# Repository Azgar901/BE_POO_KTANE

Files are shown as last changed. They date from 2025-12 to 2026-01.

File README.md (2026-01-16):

# Rapport du BE C++ : Projet  KTANE 

Basé sur le jeu vidéo de coopération "Keep Talking And Nobody Explodes"

Le code de la Mega se trouve dans le dossier Projet_KTANE tandis que le code de l'ESP8266 se trouve dans le dossier ESP8266
## La bombe et sa composition

La bombe correspond à une classe ( Bomb ) comportant la durée du jeu et le nombre d'erreurs.
Pour éviter certains problèmes, nous avons ajouté un entier Update se mettant à jour pour chaque erreur.

Les modules de la bombe seront constitués d'un module de base servant à tous, puis par héritage chaque module sera défini.

### Module Timer et Gestion des erreurs

Ce module vise à définir la gestion du temps et des erreurs.

Il utilise les pins 38 et 53 pour les LEDs des erreurs et les pins 2 et  3 ( Digital PWM ) pour l'affichage ( Timer et Erreur ).
Les modules appellent la fonction AddError() pour ajouter une erreur sur la bombe. 
Le Timer se met à jour avec l'aide de la fonction millis() pour avoir de la précision.
Quand le Timer arrive à zéro la bombe fait un son d'explosion.

Les erreurs sont gérées dans la classe Bomb, où a chaque boucle on vérifie s'il y a eu une update, à ce moment, on allume une LED supplémentaire selon le nombre d'erreurs précédentes et on affiche Err 1 ou Err 2 pendant 1s.
Au bout de 3 erreurs la bombe se déclenche et affiche "LOSE" ( sauf pour les fils où la bombe marque "LOSE" si le fil coupé n'est pas bon ( explosion instantanée )).
Si la bombe a trois succès alors le timer affiche "YEAH" et une musique retentit.

### Module de base

Chaque module sera un héritage de cette classe, elle ne contient que l'état de la led de validation et l'adresse de la bombe.

### Premier Module
Voici le module "Thread":

Il s'agit de la première configuration (de 5 fils) dont le vrai fil à couper est le 4ième fil s'il y a deux fils jaunes et un seul fil rouge.
Pour cela, j'ai fait une classe "Thread" qui aura principalement une fonction permettant de configurer en mode Input les 5 pins (9, 10, 11, 12 et 13) que l'on utilisera pour les fils et une fonction qui permettra de détecter, en fonction de l'état des ports d'entrée de la carte (si une des broches n'est plus alimentée) permettra de savoir si un fil est déconnecté de la broche.
Si le fil coupé n'est pas situé sur la broche 13, la bombe se déclenche sinon la LED s'allume.

La LED de validation est situé sur la pin 26.

### Deuxième Module
Module "Simon":

Broches utilisées → - 41, 43, 45, 47 pour les boutons poussoir
                    - 40 (rouge), 42 (bleu), 44 (jaune), 46 (vert) pour les 4 LEDs du module
                    - 48 pour la LED de validation
Le but de ce module est d'apppuyer sur les boutons qui flashent dans un ordre qui est prédéfini dans notre programme (tableaux des erreurs). Nous avons choisi la configuration correspondant à un nnuméro de série qui contient au moins une voyelle dans le jeu originel.

Le module se comporte de 3 façons différentes en fonction du nombre d'erreurs fait. Au début de la partie, ce sera toujours la LED rouge qui flashera toutes les 4 secondes. À chaque erreur (2 maximum) il y a un ordre de couleurs différentes. Nous avons défini l'ordre des couleurs dans des matrices différentes: Tab_Error0, Tab_Error1 et Tab_Error2. Si un joueur se trompe, il reprendra à partir de la couleur à laquelle il a échoué mais la suite ne sera pas la même que dans les autres cas.
Au bout de 3 erreurs, la bombe se déclenche.

### Troisième Module

Module "Password" :

Utilisation des broches 6 pour la communication avec la télécommande et 7 pour la LED de validation.

Le module se sert de la communication entre la Mega 2560 et l'ESP8266 en USART.
La Mega récupère les touches de la télécommande à travers le module IR et 
convertit ensuite avec la fonction Navigate() en instructions pour l'ESP.
Cela se fait au travers de l'USART 1 ( broche 18 ) de la MEGA ( en Tx ) et en D5 ( Rx SoftWare) pour l'ESP. 
L'envoi de l'instruction se fait à travers une surcharge d'opérateur (>>) pour simplifier la lisibité du code de Telecommmand_Check().

Concernant le code de l'ESP, la Mega fournit les instructions à travers la fonction Navigate() et Put_Letter() et l'ESP récupère les instructions, compare le premier mot d'instruction et agit, pour la télécommande cela correspond à l'instruction "SET:".
Cela nous a permis d'ajouter un module Speaker dépendant de la classe Password en ajoutant l'instruction "PLAY:".

Les instructions de la télécommande sont décomposés en 3 parties : le nom de la commande, l'emplacement de la lettre à changer et la lettre à mettre.
Ainsi, sur l'écran LCD, on peut voir les lettres envoyées apparaitre, et celles-ci sont changés si l'on appuie sur la touche Up ou Down. 
On peut contrôler l'emplacement de la lettre avec les touches fast forward et fast backward. La validation du mot de passe s'effectue avec la touche EQ.

## Problèmes rencontrés

### Pour la Bombe

Sur le plan fonctionnel, nous avons voulu gérer les erreurs et le déclenchement de la bombe par exceptions. Cependant, nous nous sommes rendu compte qu'il nous était impossible de le faire car la carte que nous avons utilisé en plus pour notre projet (Arduino MEGA) ne contient pas le runtime d’exceptions AVR qui permet de linker avec try et catch. On a du donc abandonné l'idée.

### Pour le timer

Compliqué à mettre en place, nous avions d'abord prévu de le faire par interruption, mais cela rendait le code très compliqué et il aurait fallu faire les autres fonctions par interruption. 
On a donc changé pour la fonction millis() plus simple d'utilisation. Cela permet au Timer de ne jamais se bloquer. 

L'affichage n'était pas simple, nous voulions à la base utilisée la surcharge d'opérateur pour décompter le timer mais cela ne menait qu'à davantage de difficulté inutile.
Alors, nous avons juste utilisé un int permettant de décompter.

### Pour les Fils

Difficulté de réalisation, les fils utilisent la fonction output pullup des gpios mais nous voulions faire l'inverse ( si l'état est bas alors le fil est coupé )
mais cela créait des broches flottantes qui n'étaient pas détectées.

### Pour le Simon

Difficulté de compréhension, nous avons dû revoir tout notre code sur un tableau ( toute une après-midi ) pour être sûr de ce qu'on faisait et que nous soyons clairs sur la démarche du module.
La gestion de clignotement des leds étaient aussi compliqués dans la logique de gestion ( selon si on appuie sur un bouton ou non ) faisant appel de nombreuses fois à la fonction millis.

### Pour le Password

Difficulté de syntaxe, première utilisation du module IRreceiver ayant une syntaxe particulière puis affichage sur le LCD avec la carte ESP8266.
Nous avons aussi voulu utilisé la STL dans le code pour avoir l'algorithme d'égalité de deux tableaux sauf que la MEGA ne supporte pas ArduinoSTL, nous avons donc décidé de ne pas l'utiliser.

### Pour la sortie audio

Nous voulions absolument une sortie audio pour la bombe, premier essai sans amplificateur audio ( seulement un transistor NPN ) et en wifi. Le résultat est un son très faible avec plus de grésillements que de signal voulu. 
Avec l'utilisation de l'amplificateur audio le son n'était que plus fort et nous avons du oublié l'utilisation du wifi pour l'audio.

Après ces échecs, nous avons essayé de mettre la partie audio sur la Mega mais celle-ci n'a pas assez de mémoire flash donc deuxième abandon.

Nous avons donc repris l'ESP8266 et avons découvert la librairie LittleFS pas trop complexe d'utilisation et qui permet d'envoyer un fichier directement dans la mémoire de l'ESP.

# Partie Conception

La bombe a été créé à partir de casier de rangement imprimé en 3D par nos soins avec l'utilisation du modèle STL " Interlocking Drawer " trouvé sur Thingiverse : https://www.thingiverse.com/thing:2539830.
Nous avons apporté des modifications au fichier de base ( notamment l'ouverture interne de la carte ).

La conception de l'intérieur a été faite sur-mesure en fonction des composants de chaque module, toujours imprimé en 3D permettant de faire des essais/erreurs.
La conception nous a permis de nous faire continuer d'apprendre la modélisation 3D.

Tous les fichiers STL et 3mf ( dont les erreurs )sont dans le dossier 3D File.

Les boutons ont ensuite été soudé avec les câbles et nous avons torsadé les câbles autour des lEDS ( LED + résistance ).

## Difficultés rencontrées

La gestion interne de la bombe a été compliqué, il a fallu concevoir une architecture solide mais permettant une modularité si l'on veut changer les modules( d'où l'utilisation de casier encastré ) même si cette idée a été un peu abandonnée par manque de temps.

Il a fallu ensuite prendre les mesures de chaque composant et faire des tests lors de la création interne modules pour être sûr que le composant pouvait rester en place.

L'écran LCD a posé des problèmes car il est plus grand que le casier, nous avons donc dû modifier davantage le fichier STL pour créer une encoche sur le dessus et adapter l'intérieur du casier pour pouvoir ajouter la LED et le module IR.

Le plus gros problème a été l'assemblage final et cela venait de l'utilisation des casiers modulables car pour assembler les casiers il faut les encaster par le haut ou le bas.
Ce que nous n'avions pas pris en compte a été le nombre total de fils. Il fallait que tous les fils restent connectés mais nous avons majoritairement utilisés des fils Dupont mâle-mâle ou mâle-femelle ce qui n'aidaient pas au maintien.
Nous avons donc commencé par le Simon ( le plus cablé et moins accessible ), facile à faire mais il a ensuite fallu connecter le timer et placer la Mega à l'intérieur. 
Ici vient deux problèmes : les câbles du Simon se détachent et la carte passe à peine dans son encadrement prévu ( entre les 4 modules ). Nous avons donc dû à de nombreuses reprises rebrancher les fils à la pincette puis percé un trou pour la Mega.
Nous avons ensuite eu des difficultés à placer les deux derniers casiers car il fallait lever la carte pour faire passer les casiers par le haut et le tout sans débrancher les câbles déjà placés, parce qu'ils ne seront plus accessibles.

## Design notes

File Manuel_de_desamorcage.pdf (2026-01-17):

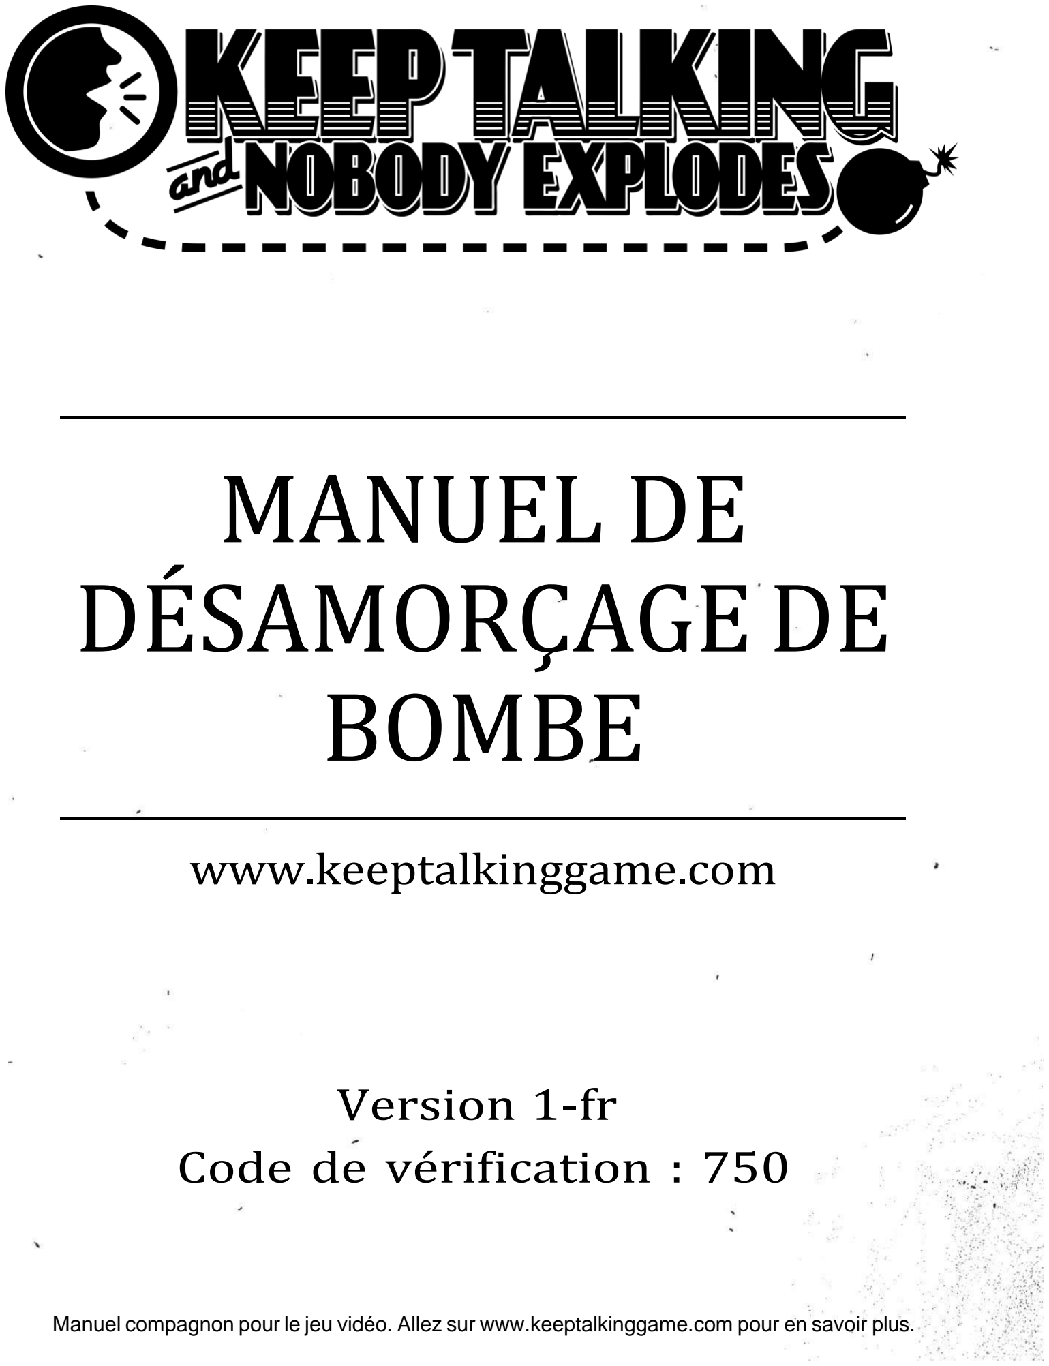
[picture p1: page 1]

# MANUEL DE DÉSAMORÇAGE DE BOMBE

# www.keeptalkinggame.com

# Version 1-fr Code de vérification : 750

Manuel compagnon pour le jeu vidéo. Allez sur www.keeptalkinggame.com pour en savoir plus.

Keep Talking and Nobody Explodes v. 1-fr | Introduction

Bienvenue dansle monde dangereux et difficile des désamorceurs de bombes.

ÉtudieZ ce manuel attentivement ; vous êtesl'expert. Dans ces pages, voustrouvereZ toutes les informations nécessaires pour désamorcer même les bombes les plus coriaces.
Et n'oublieZ pas — un seul oubli et tout pourrait se terminer ! Bonne chance !
Matérialisée par LELENGOLI Bernys et MELADE Ulrich. Nos remerciements à BENOIT Arwen.

Page l

# Désarmorcer des bombes

Une bombe explose lorsque son compte à rebours atteint 0:00 ou lorsque trop d'erreurs ont été commises. Le seul moyen de désamorcer une bombe avant qu'elle n'explose est de désarmer chaque module séparément avant que le compte à rebours ne se termine.

Exemple d'une bombe

Face | Côté

Modules

Chaque bombe aura jusqu'à 11 modules qui devront être désarmés. Chaque module est indépendant. Ils peuvent être désamorcés dans n'importe quel ordre.

Les instructions pour désarmer les modules peuvent être trouvées dans la Section
1. Les modules "Demandants" sont une exception et sont décrits dans la Section l.

Erreurs

Si le désamorceur fait une erreur, la bombe enregistre une erreur qui
est montrée au-dessus du compte à rebours. Les bombes avec un compteur d'erreur exploseront à la troisième erreur. Le compte à rebours ira plus vite à chaque erreur commise.

Indicateur
d'erreur

S'il n'y a pas d'indicateur au-dessus du compte à rebours, la bombe explosera à la première faute commise, ne laissant aucune place à l'erreur.

Obtenir des informations

Certaines instructions pour désarmer des modules nécessiteront des informations spécifiques sur la bombe, comme le numéro de série. Ce type d'information se trouve typiquement sur les côtés de la bombe. Se référer aux annexes A, B et C pour plus d'informations d'identification qui seront utiles pour désarmer certains modules.

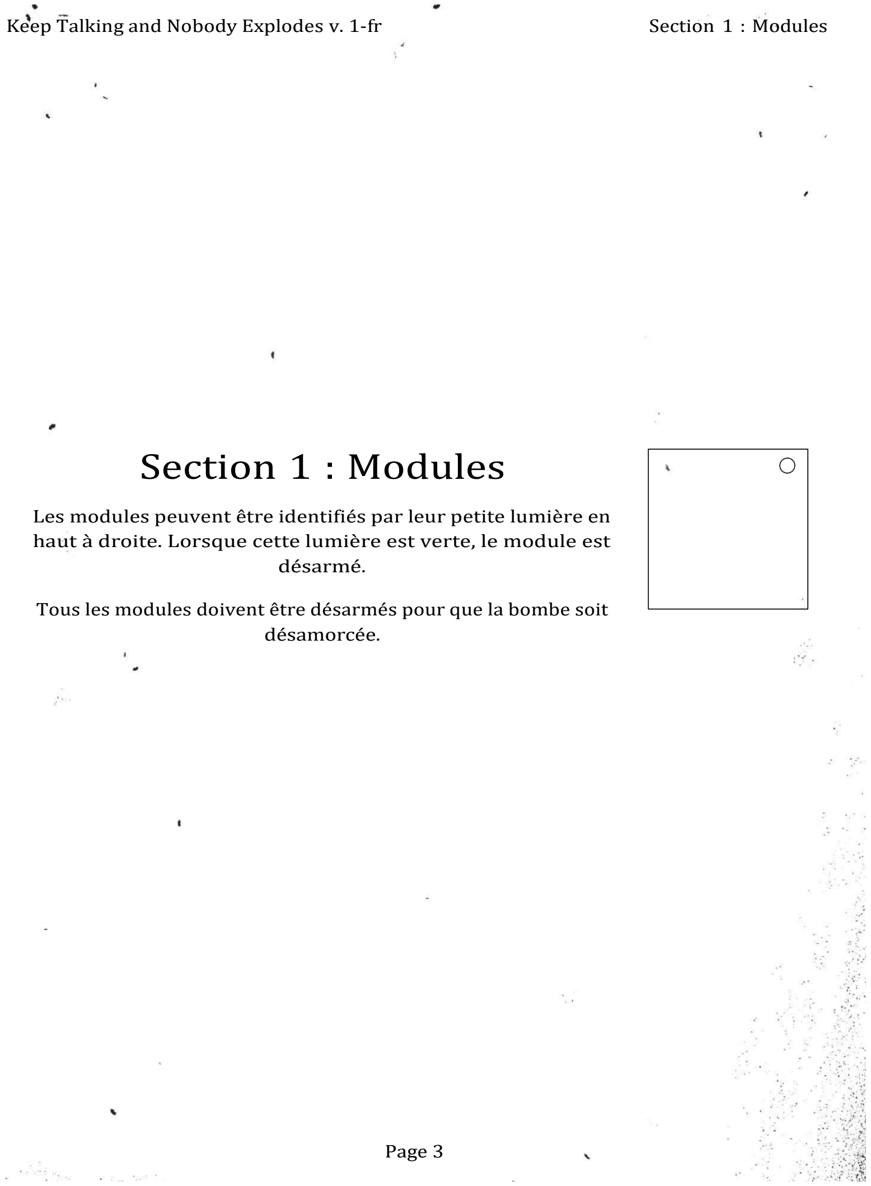
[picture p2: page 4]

Keep Talking and Nobody Explodes v. 1-fr | Section 1 : Modules

# Section 1 : Modules

Les modules peuvent être identifiés par leur petite lumière en haut à droite. Lorsque cette lumière est verte, le module est désarmé.

Tous les modules doivent être désarmés pour que la bombe soit désamorcée.

Keep Talking and Nobody Explodes v. 1-fr | Fils

## À propos des Fils

Lesfilssont comme le sang de l'électronique ! Non... L'électricité est le sang. Lesfils sont plus comme les artères. Les veines ? Peu importe...

Un module de fils peut contenir entre 3 et 6 fils.
Seul un fil a besoin d'être coupé pour désarmer le module. Les fils sont ordonnés de haut en bas.

3 fils :
S'il n'y a pas de fil rouge, couper le troisième fil.
Sinon, si le dernier fil est blanc, couper le premier fil. Sinon, s'il y a plus d'un fil bleu, couper le dernier fil rouge.
Sinon, couper le quatrième fil.

4 fils :
S'il y a plus d'un fil rouge et si le dernier chiffre du numéro de série est
impair, couper le dernier fil jaune.
Sinon, si le dernier filestjaune et s'il n'y a pas de fil blanc, couper le dernier fil. Sinon, s'il y a exactement un fil bleu, couper le.
Sinon, s'il y a plus d'un fil jaune, couper le premier fil.
Sinon, couper le troisième fil.

5 fils :
Si le dernier filest vertet si le dernier chiffre du numéro de série est impair, couper le dernier fil.
Sinon, s'il y a exactement un fil blanc et plus d'un fil jaune, couper le premier fil.
Sinon, s'il n'y a pas de fil noir, couper le premier fil.
Sinon, couper le cinquième fil.

6 fils :
S'il n'y a pas de fil bleu et si le dernier chiffre du numéro de série est impair, couper le deuxième fil.
Sinon, s'il y a exactement un fil noir et plus d'un fil blanc, couper le troisième fil. Sinon, s'il n'y a pas de fil rouge, couper le premier fil.
Sinon, couper le cinquième fil.

Keep Talking and Nobody Explodes v. 1-fr | Bouton

## À propos du Bouton

On pourrait penser qu'appuyer sur un bouton est asseZ simple. C'est en pensant de cette façon que des bombes explosent.

Se référer à l'annexe A pour identifier les indicateurs.
Se référer à l'annexe B pour identifier les piles.

Suivre ces règles dans l'ordre dans lequel elles sont listées.
Effectuer la première action qui répond aux critères :
1. Si le bouton est bleu et est marqué « Annuler », maintenir le bouton appuyé et se référer à « Relâcher un bouton enfoncé ».
l. S'il y a plus d'une pile sur la bombe et si le bouton est marqué « Exploser », appuyer et immédiatement relâcher le bouton.
3. Si le bouton est blanc et s'il y a un indicateur allumé avec les lettres CAR, maintenir le bouton appuyé et se référer à « Relâcher un bouton enfoncé ».
4. S'il y a plus de deux piles sur la bombe et s'il y a un indicateur allumé avec les lettres FRK, appuyer et immédiatement relâcher le bouton.
5. Si le bouton est jaune, maintenir le bouton appuyé et se référer à « Relâcher un bouton enfoncé ».
6. Si le bouton est rouge et est marqué « Maintenir », appuyer et immédiatement relâcher le bouton.
7. Si aucune des règles ne correspond, maintenir le bouton appuyé et se référer à « Relâcher un bouton enfoncé ».

Relâcher un bouton enfoncé

Lors de l'appui sur le bouton, une bande colorée s'allume sur le côté droit du module. Relâcher alors le bouton à un moment spécifique en fonction de la couleur de cette bande :

Bande bleue : relâcher lorsque le compte à rebours affiche un 4 à n'importe quelle position.
Bande blanche : relâcher lorsque le compte à rebours affiche un 1 à n'importe quelle position.
Bande jaune : relâcher lorsque le compte à rebours affiche un 5 à n'importe quelle position.
Bande d'une autre couleur : relâcher lorsque le compte à rebours affiche un 1 à n'importe quelle position.

## À propos du Clavier

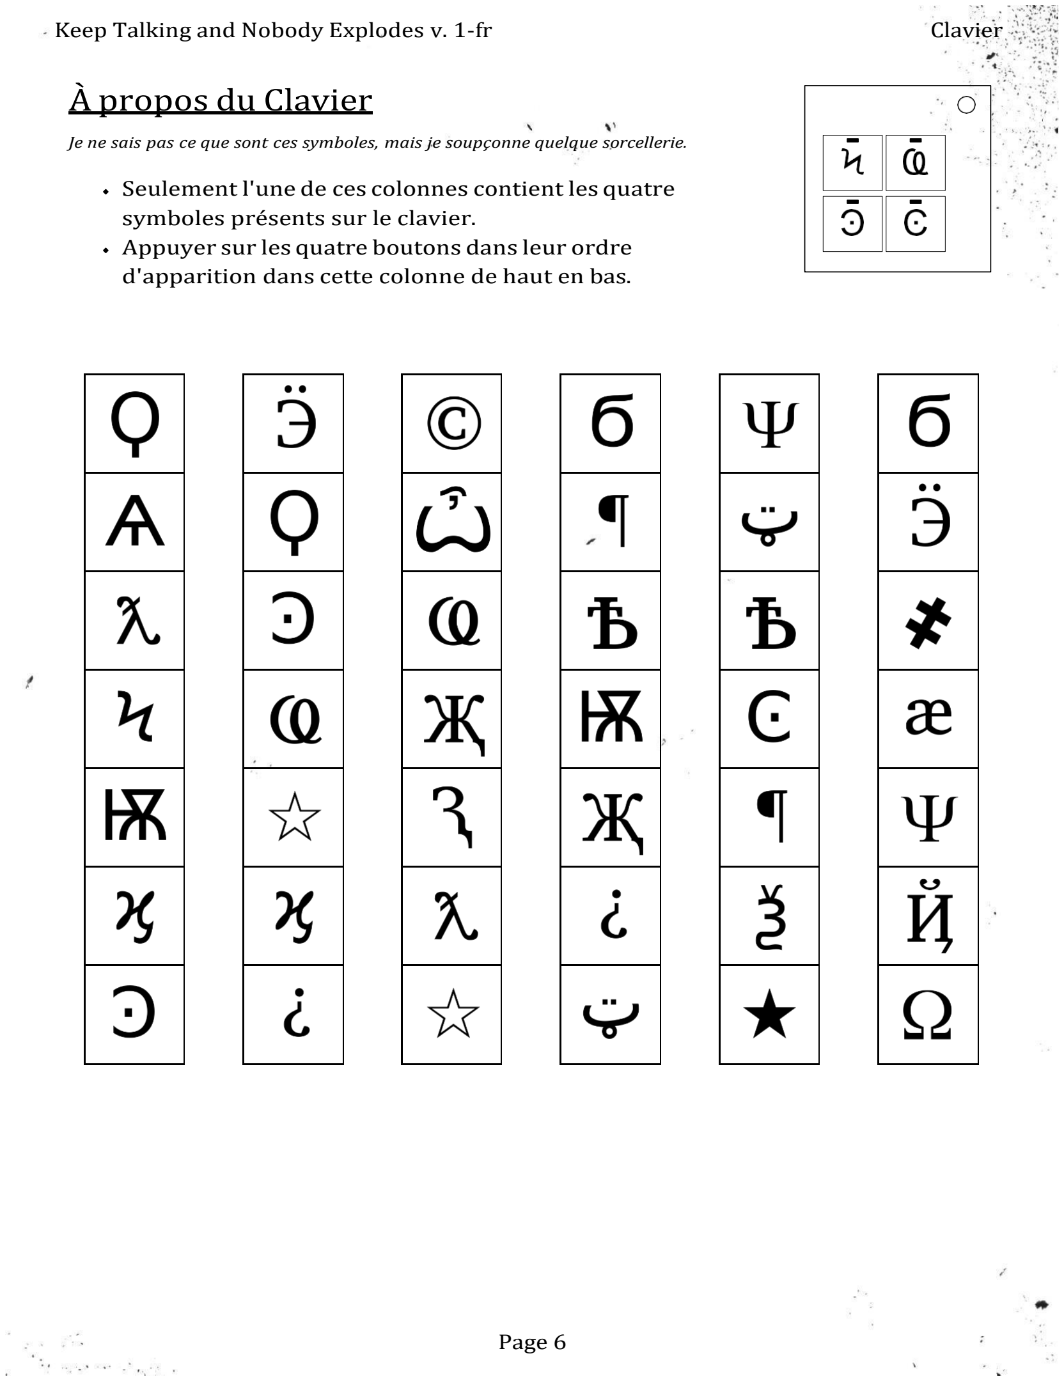
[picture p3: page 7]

Keep Talking and Nobody Explodes v. 1-fr | Clavier

Je ne sais pas ce que sont ces symboles, mais je soupçonne quelque sorcellerie.

Seulement l'une de ces colonnes contient les quatre symboles présents sur le clavier.
Appuyer sur les quatre boutons dans leur ordre d'apparition dans cette colonne de haut en bas.

Keep Talking and Nobody Explodes v. 1-fr | Simon

## À propos du Simon

Les modules peuvent être identifiés par leur petite lumière en haut à droite. Lorsque cette lumière est verte, le module est désarmé.

1. Un des quatre boutons s'allumera.
l. En utilisant la table ci-dessous, appuyer sur le bouton correspondant.
3. Le bouton original s'allumera suivi d'un autre. Répéter la
séquence dans l'ordre en utilisantla correspondance des couleurs.
4. La séquence s'allongera d'une couleur à chaque fois que la bonne séquence sera entrée, jusqu'à ce que le module soit désarmé.

## Rouge Vert

## Bleu Jaune

Si le numéro de série contient au moins une voyelle :

Flash Rouge | Flash Bleu | Flash Vert | Flash Jaune
Bouton à appuyer : | Pas d'erreur | Bleu | Rouge | Jaune | Vert
| 1 erreur | Jaune | Vert | Bleu | Rouge
| l erreurs | Vert | Rouge | Jaune | Bleu

Si le numéro de série ne contient pas de voyelle :

Flash Rouge | Flash Bleu | Flash Vert | Flash Jaune
Bouton à appuyer : | Pas d'erreur | Bleu | Jaune | Vert | Rouge
| 1 erreur | Rouge | Bleu | Jaune | Vert
| l erreurs | Jaune | Vert | Bleu | Rouge

## À propos du Labyrinthe

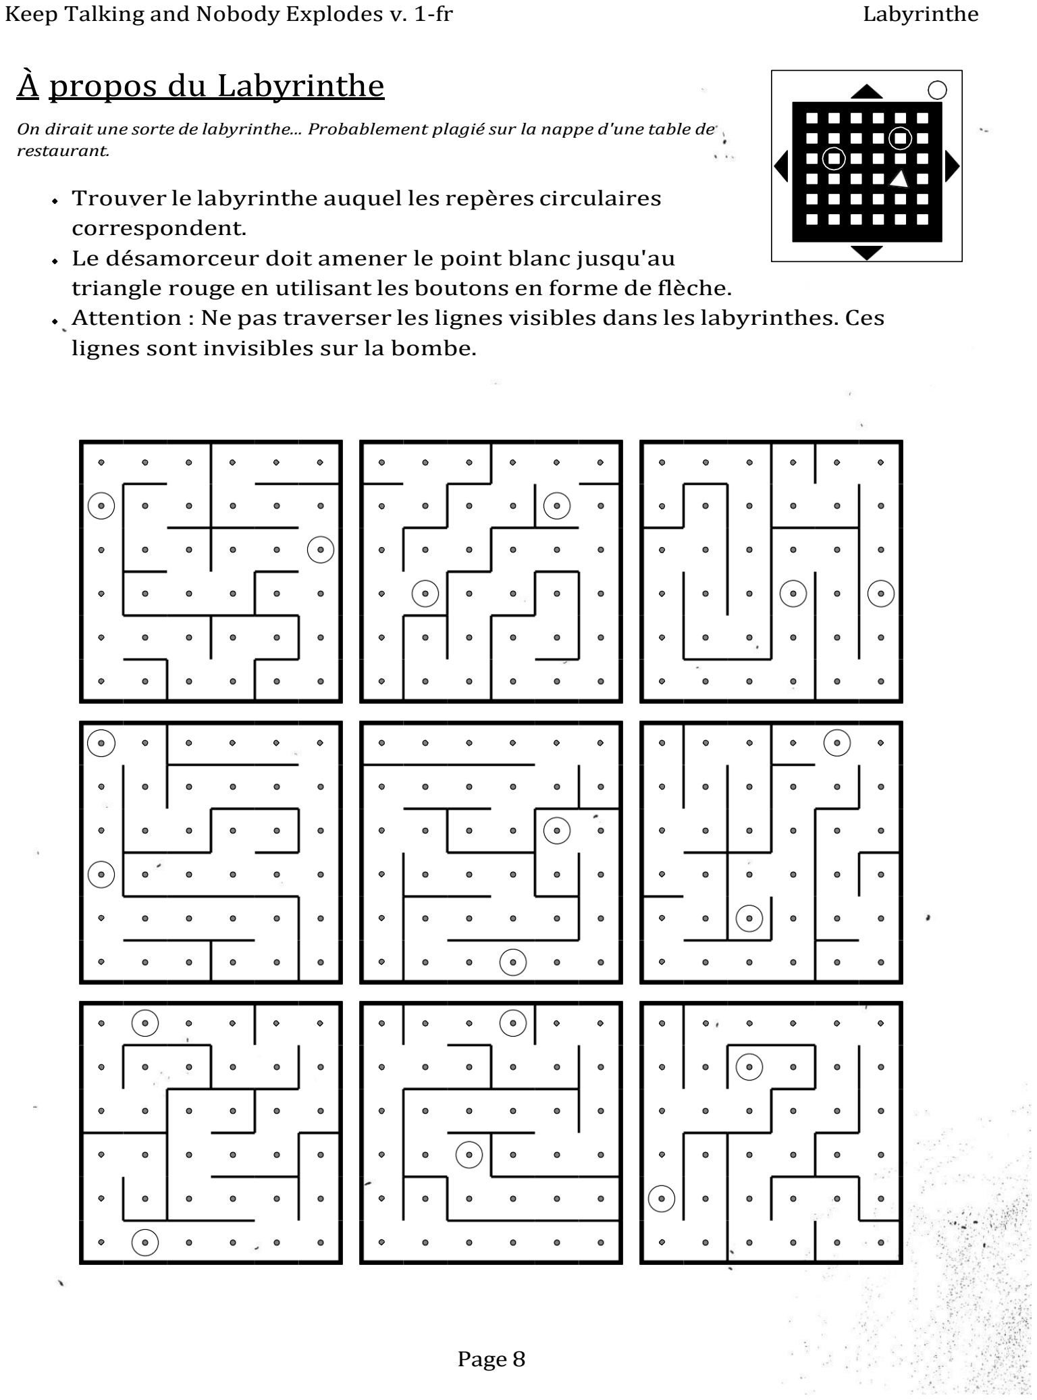
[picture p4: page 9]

Keep Talking and Nobody Explodes v. 1-fr | Labyrinthe

On dirait une sorte de labyrinthe... Probablement plagié sur la nappe d'une table de restaurant.

Trouver le labyrinthe auquel les repères circulaires correspondent.
Le désamorceur doit amener le point blanc jusqu'au
triangle rouge en utilisant les boutons en forme de flèche.
Attention : Ne pas traverser les lignes visibles dans les labyrinthes. Ces lignes sont invisibles sur la bombe.

## À propos de Jeux de mots

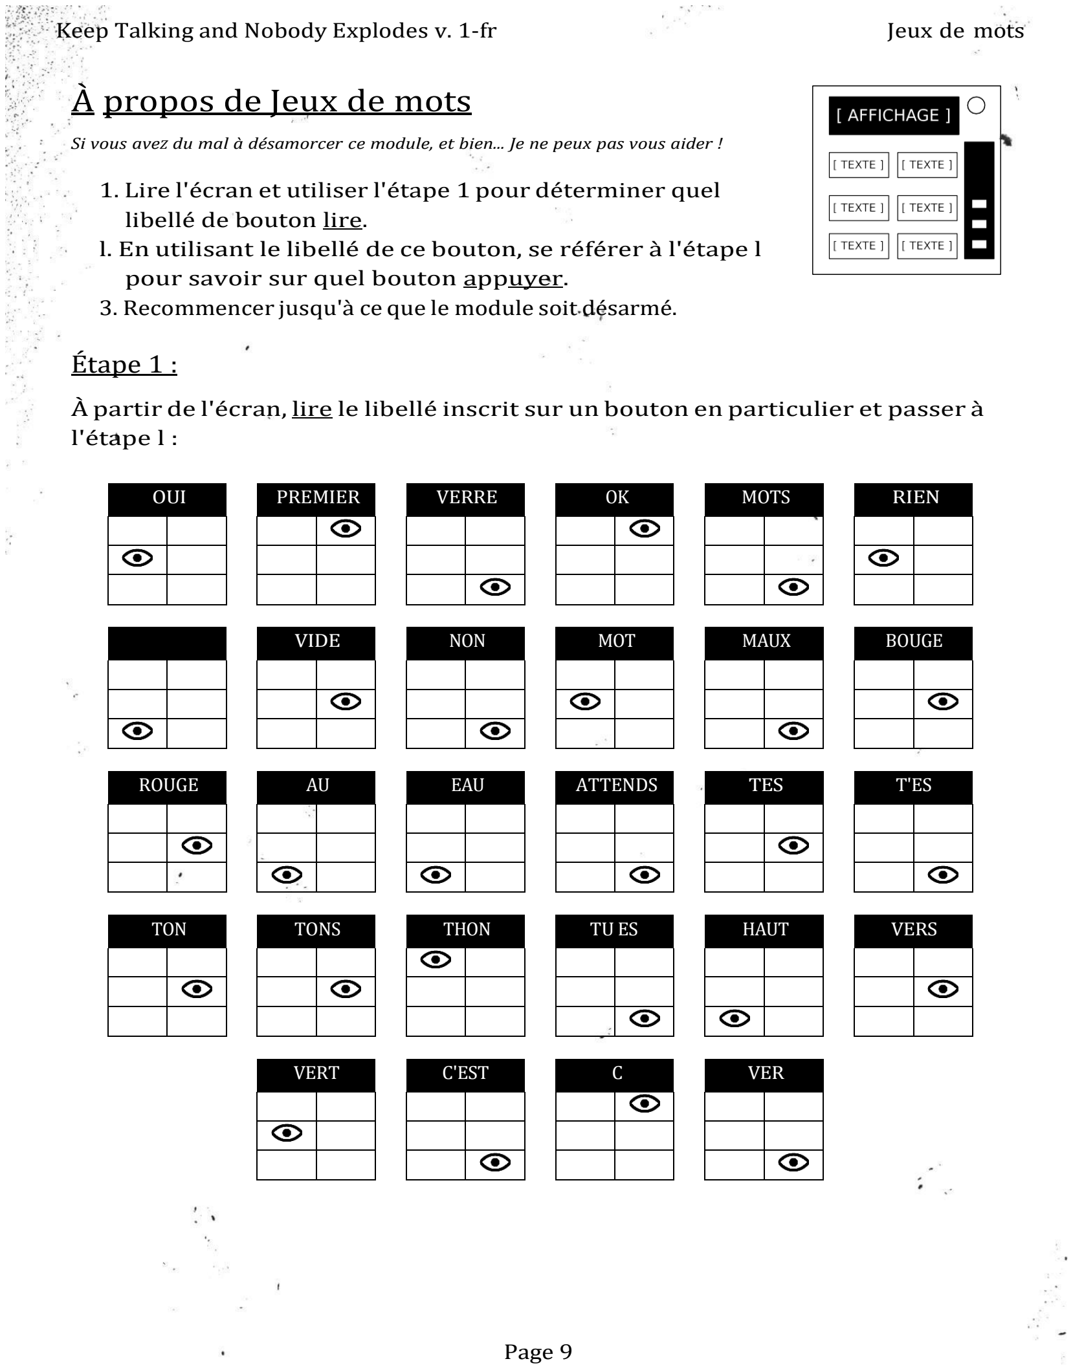
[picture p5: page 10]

Keep Talking and Nobody Explodes v. 1-fr | Jeux de mots

Si vous aveZ du mal à désamorcer ce module, et bien... Je ne peux pas vous aider !

1. Lire l'écran et utiliser l'étape 1 pour déterminer quel libellé de bouton lire.
l. En utilisant le libellé de ce bouton, se référer à l'étape l pour savoir sur quel bouton appuyer.
3. Recommencer jusqu'à ce que le module soit désarmé.

Étape 1 :

À partir de l'écran, lire le libellé inscrit sur un bouton en particulieret passerà l'étape l :

OUI | PREMIER | VERRE | OK | MOTS | RIEN
VIDE | NON | MOT | MAUX | BOUGE
ROUGE | AU | EAU | ATTENDS | TES | T'ES
TON | TONS | THON | TU ES | HAUT | VERS
VERT | C'EST | C | VER

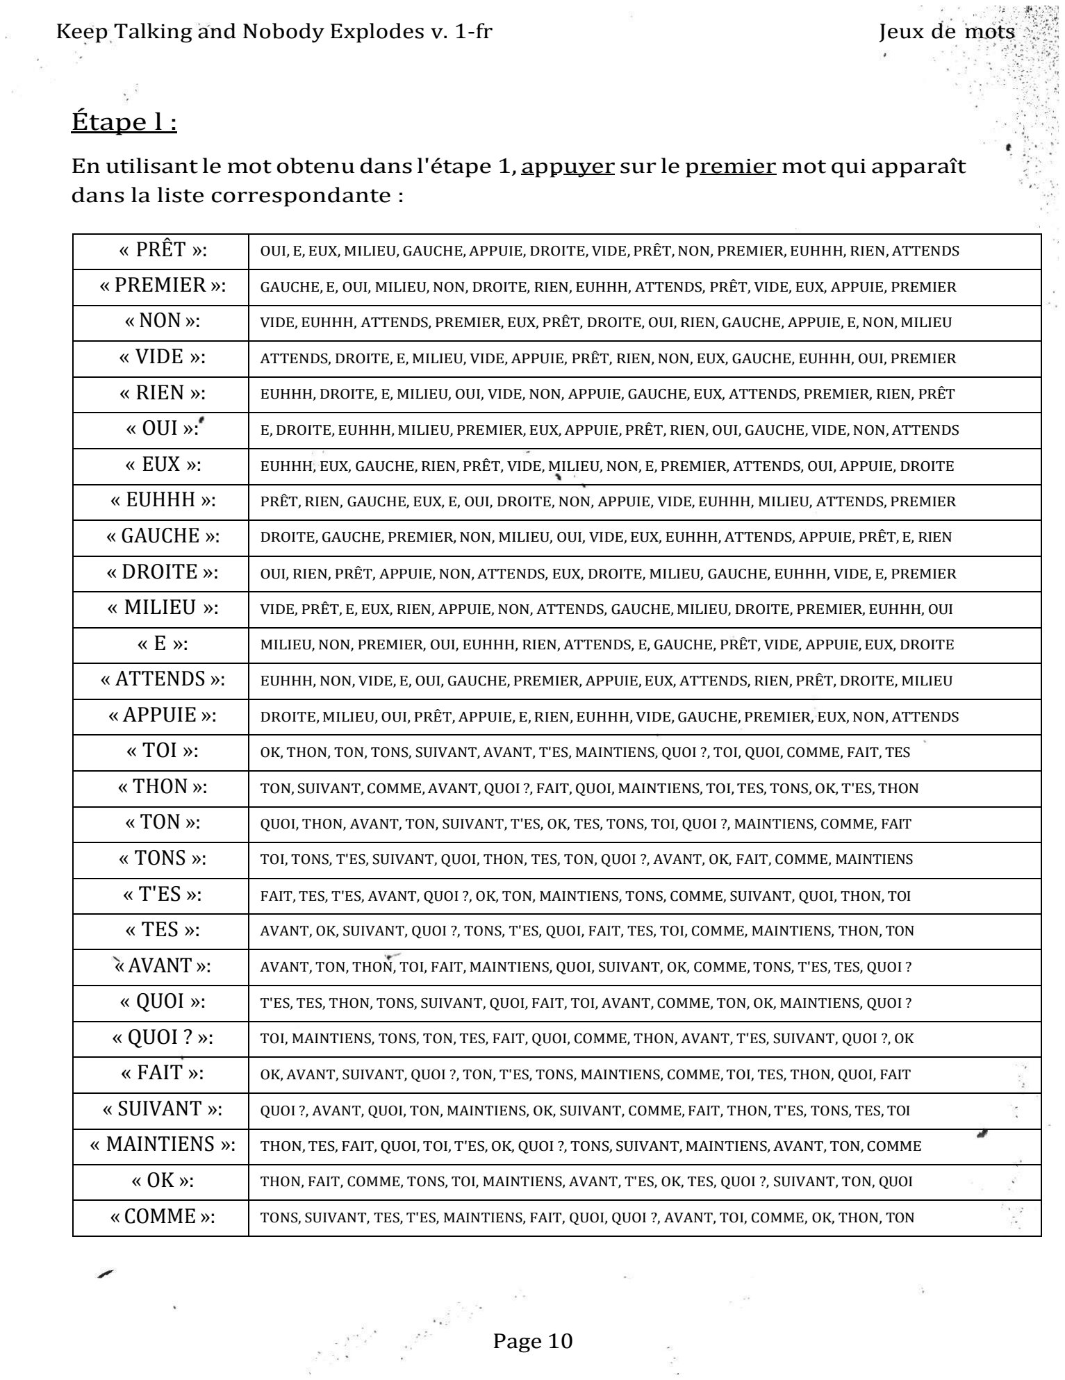
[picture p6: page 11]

Keep Talking and Nobody Explodes v. 1-fr | Jeux de mots

Étape l :

En utilisantle mot obtenu dans l'étape 1, appuyer sur le premier mot qui apparaît dans la liste correspondante :

« PRÊT »: | OUI, E, EUX, MILIEU, GAUCHE, APPUIE, DROITE, VIDE, PRÊT,NON, PREMIER, EUHHH, RIEN, ATTENDS
« PREMIER »: | GAUCHE, E, OUI, MILIEU, NON, DROITE, RIEN, EUHHH, ATTENDS, PRÊT, VIDE, EUX, APPUIE, PREMIER
« NON»: | VIDE, EUHHH, ATTENDS, PREMIER, EUX, PRÊT, DROITE, OUI, RIEN, GAUCHE, APPUIE, E,NON, MILIEU
« VIDE »: | ATTENDS, DROITE, E, MILIEU, VIDE, APPUIE, PRÊT, RIEN, NON, EUX, GAUCHE, EUHHH, OUI, PREMIER
« RIEN »: | EUHHH, DROITE, E, MILIEU, OUI, VIDE, NON, APPUIE, GAUCHE, EUX, ATTENDS, PREMIER, RIEN, PRÊT
« OUI »: | E,DROITE, EUHHH, MILIEU, PREMIER, EUX, APPUIE, PRÊT, RIEN, OUI, GAUCHE, VIDE,NON, ATTENDS
« EUX »: | EUHHH, EUX, GAUCHE, RIEN, PRÊT, VIDE, MILIEU, NON, E, PREMIER, ATTENDS, OUI, APPUIE, DROITE
« EUHHH »: | PRÊT, RIEN, GAUCHE, EUX, E, OUI, DROITE, NON, APPUIE, VIDE, EUHHH, MILIEU, ATTENDS, PREMIER
« GAUCHE »: | DROITE, GAUCHE, PREMIER, NON, MILIEU, OUI, VIDE, EUX, EUHHH, ATTENDS, APPUIE, PRÊT, E, RIEN
« DROITE »: | OUI, RIEN, PRÊT, APPUIE, NON, ATTENDS, EUX, DROITE, MILIEU, GAUCHE, EUHHH, VIDE, E, PREMIER
« MILIEU »: | VIDE, PRÊT, E, EUX, RIEN, APPUIE, NON, ATTENDS, GAUCHE, MILIEU, DROITE, PREMIER, EUHHH, OUI
« E »: | MILIEU, NON, PREMIER, OUI, EUHHH, RIEN, ATTENDS, E, GAUCHE, PRÊT, VIDE, APPUIE, EUX, DROITE
« ATTENDS »: | EUHHH, NON, VIDE, E, OUI, GAUCHE, PREMIER, APPUIE, EUX, ATTENDS, RIEN, PRÊT, DROITE, MILIEU
« APPUIE »: | DROITE, MILIEU, OUI, PRÊT, APPUIE, E, RIEN, EUHHH, VIDE, GAUCHE, PREMIER, EUX,NON, ATTENDS
« TOI »: | OK, THON, TON, TONS, SUIVANT, AVANT, T'ES, MAINTIENS, QUOI ?, TOI, QUOI, COMME, FAIT, TES
« THON »: | TON, SUIVANT, COMME, AVANT, QUOI ?, FAIT,QUOI, MAINTIENS, TOI, TES, TONS, OK, T'ES, THON
« TON »: | QUOI, THON, AVANT, TON, SUIVANT, T'ES, OK, TES, TONS, TOI, QUOI ?, MAINTIENS, COMME, FAIT
« TONS »: | TOI, TONS, T'ES, SUIVANT, QUOI, THON, TES, TON, QUOI ?, AVANT, OK, FAIT, COMME, MAINTIENS
« T'ES »: | FAIT, TES, T'ES, AVANT, QUOI ?, OK, TON, MAINTIENS, TONS, COMME, SUIVANT, QUOI, THON, TOI
« TES »: | AVANT, OK, SUIVANT, QUOI ?, TONS, T'ES, QUOI, FAIT, TES, TOI, COMME, MAINTIENS, THON, TON
«AVANT »: | AVANT, TON, THON, TOI, FAIT, MAINTIENS, QUOI, SUIVANT, OK, COMME, TONS, T'ES, TES, QUOI ?
« QUOI »: | T'ES, TES, THON, TONS, SUIVANT, QUOI, FAIT, TOI, AVANT, COMME, TON, OK, MAINTIENS, QUOI ?
« QUOI ? »: | TOI, MAINTIENS, TONS, TON, TES, FAIT, QUOI, COMME, THON, AVANT, T'ES, SUIVANT, QUOI ?, OK
« FAIT »: | OK, AVANT, SUIVANT, QUOI ?, TON, T'ES, TONS, MAINTIENS, COMME, TOI, TES, THON, QUOI, FAIT
« SUIVANT »: | QUOI ?, AVANT, QUOI, TON, MAINTIENS, OK, SUIVANT, COMME, FAIT, THON, T'ES, TONS, TES, TOI
« MAINTIENS »: | THON,TES, FAIT, QUOI, TOI, T'ES, OK, QUOI ?, TONS, SUIVANT, MAINTIENS, AVANT, TON, COMME
« OK »: | THON, FAIT, COMME, TONS, TOI, MAINTIENS, AVANT, T'ES, OK, TES, QUOI ?, SUIVANT, TON, QUOI
« COMME »: | TONS, SUIVANT, TES, T'ES, MAINTIENS, FAIT, QUOI, QUOI ?, AVANT, TOI, COMME, OK, THON, TON

Keep Talking and Nobody Explodes v. 1-fr | Simon

## À propos du Simon

Les modules peuvent être identifiés par leur petite lumière en haut à droite. Lorsque cette lumière est verte, le module est désarmé.

1. Un des quatre boutons s'allumera.
l. En utilisant la table ci-dessous, appuyer sur le bouton correspondant.
3. Le bouton original s'allumera suivi d'un autre. Répéter la
séquence dans l'ordre en utilisant la correspondance des couleurs.
4. La séquence s'allongera d'une couleur à chaque fois que la bonne séquence sera entrée, jusqu'à ce que le module soit désarmé.

## Rouge Vert

## Bleu Jaune

Si le numéro de série contient au moins une voyelle :

Flash Rouge | Flash Bleu | Flash Vert | Flash Jaune
Bouton à appuyer : | Pas d'erreur | Jaune | Vert | Bleu | Rouge
| 1 erreur | Bleu | Jaune | Vert | Rouge
| 2 erreurs | Rouge | Bleu | Jaune | Vert

Si le numéro de série ne contient pas de voyelle :

Flash Rouge | Flash Bleu | Flash Vert | Flash Jaune
Bouton à appuyer : | Pas d'erreur | Jaune | Rouge | Bleu | Vert
| 1 erreur | Bleu | Jaune | Rouge | Vert
| 2 erreurs | Vert | Bleu | Jaune | Rouge

Keep Talking and Nobody Explodes v. 1-fr | Memory

## À propos du Memory

La mémoire est une chose fragile, mais bon tout l’est quand une bombe explose, alors faites attention !

Appuyer sur la bonne touche pour aller à la prochaine étape. Compléter toutes les étapes pour désarmer le module. Appuyer sur un bouton incorrect vous fera revenir à l'étape 1.
Les boutons sont ordonnés de gauche à droite.

Étape 1 :

Si l'écran affiche 1, appuyer sur le bouton en deuxième position. Si l'écran affiche l, appuyer sur le bouton en deuxième position. Si l'écran affiche 3, appuyer sur le bouton en troisième position. Si l'écranaffiche 4, appuyer sur le bouton en quatrième position.

Étape l :

Si l'écran affiche 1, appuyer sur le bouton portant le chiffre « 4 » .
Si l'écran affiche l, appuyer sur le bouton à la même positionqu'à l'étape 1. Si l'écran affiche 3, appuyer sur le bouton en première position.
Si l'écran affiche 4, appuyer sur le bouton à la même position qu'à l'étape 1.

Étape 3 :

Si l'écran affiche 1, appuyer sur le bouton ayant le même chiffre qu'à l'étape l. Si l'écran affiche l, appuyer sur le bouton ayant le même chiffre qu'à l'étape 1. Si l'écran affiche 3, appuyer sur le bouton en troisième position.
Si l'écran affiche 4, appuyer sur le bouton portant le chiffre « 4 » .

Étape 4 :

Si l'écran affiche 1, appuyer sur le bouton à la même position qu'à l'étape 1. Si l'écran affiche l, appuyer sur le bouton en première position.
Si l'écran affiche 3, appuyer sur le bouton à la même positionqu'à l'étape l. Si l'écran affiche 4, appuyer sur le bouton à la même position qu'à l'étape l.

Étape 5 :

Si l'écran affiche 1, appuyer sur le bouton ayant le même chiffre qu'à l'étape 1. Si l'écran affiche l, appuyer sur le bouton ayant le même chiffre qu'à l'étape l. Si l'écran affiche 3, appuyer sur le bouton ayant le même chiffre qu'à l'étape 4. Si l'écran affiche 4, appuyer sur le bouton ayant le même chiffre qu'à l'étape 3.

## À propos du Code Morse

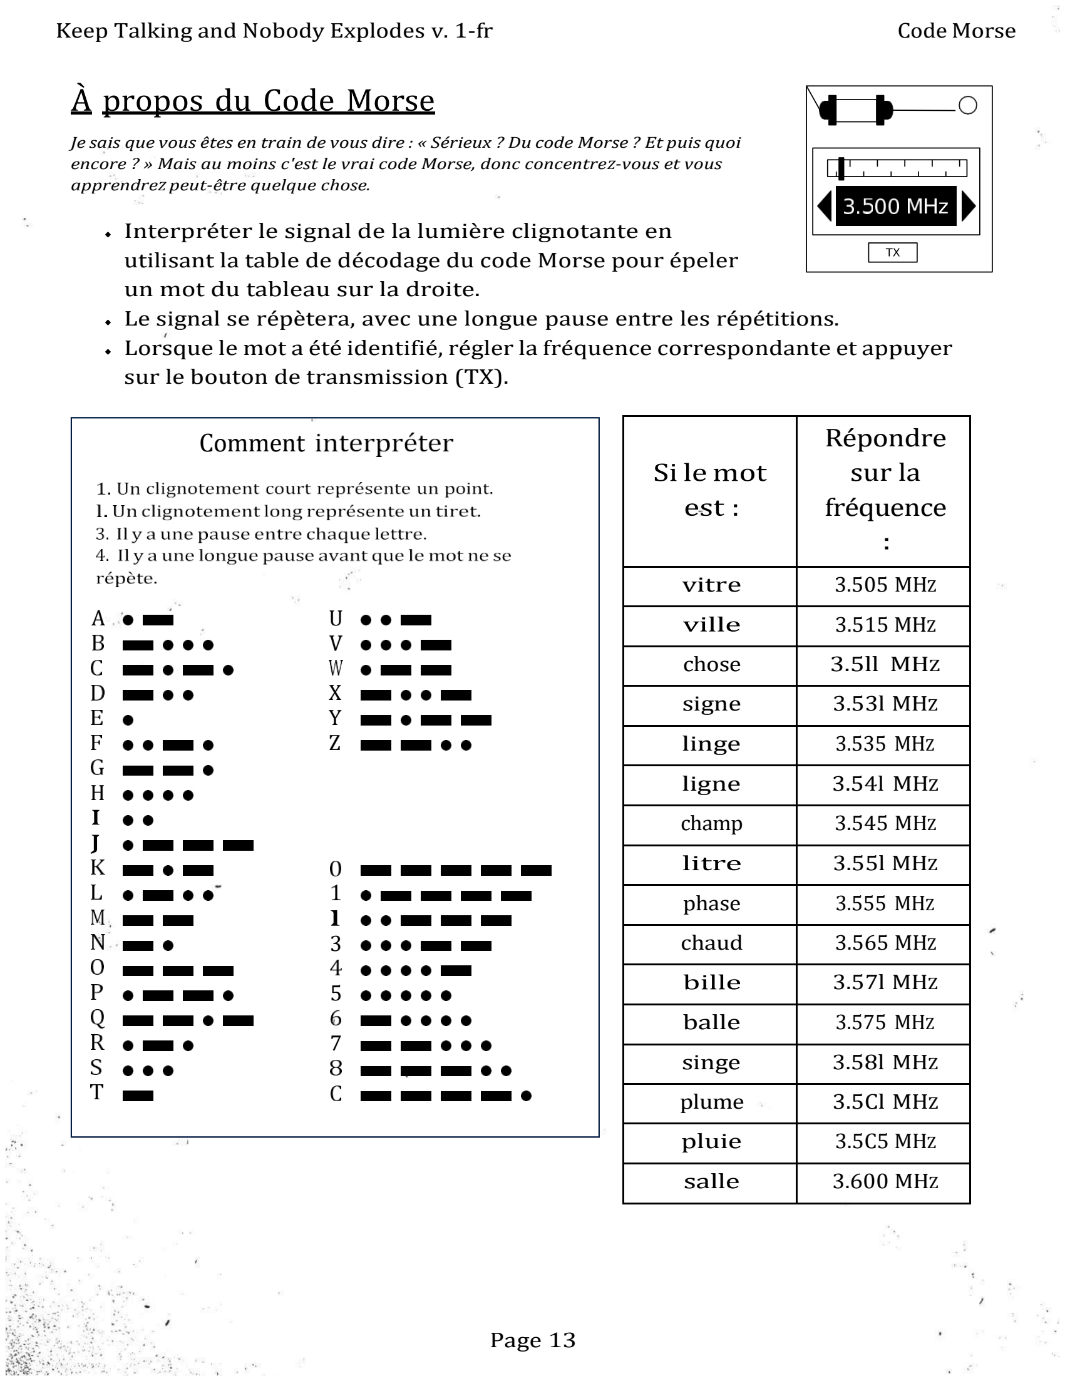
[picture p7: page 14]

### Comment

A | U V
| X Y Z

H

3

5

7

Keep Talking and Nobody Explodes v. 1-fr | Code Morse

Je sais que vous êtes en train de vous dire : « Sérieux ? Du code Morse ? Et puis quoi encore ? » Mais au moins c'est le vrai code Morse, donc concentreZ-vous et vous apprendreZ peut-être quelque chose.

Interpréter le signal de la lumière clignotante en
utilisant la table de décodage du code Morse pour épeler
un mot du tableau sur la droite.
Le signal se répètera, avec une longue pause entre les répétitions.
Lorsque le mot a été identifié, régler la fréquence correspondante et appuyer sur le bouton de transmission (TX).
Si le mot est : | Répondre sur la fréquence :
vitre | 3.505 MHZ
ville | 3.515 MHZ
chose | 3.5ll MHZ
signe | 3.53l MHZ
linge | 3.535 MHZ
ligne | 3.54l MHZ
champ | 3.545 MHZ
litre | 3.55l MHZ
phase | 3.555 MHZ
chaud | 3.565 MHZ
bille | 3.57l MHZ
balle | 3.575 MHZ
singe | 3.58l MHZ
plume | 3.5Cl MHZ
pluie | 3.5C5 MHZ
salle | 3.600 MHZ

Keep Talking and Nobody Explodes v. 1-fr | Fils compliqués

## À propos des Fils compliqués

Ces fils ne sont pas comme les autres. Ils peuvent avoir deux couleurs ! Cela les rend complètement différents. La bonne nouvelle c'est que vous aveZ à votre disposition des instructions très précises ! Peut-être trop précises...

Regarder chaque fil : il y a une lumière au-dessus et de l'espace pour le symbole « ★ » sous le fil.
Pour chaque combinaison de fil/lumière/symbole, utiliser
le diagramme de Venn pour savoir s'il faut couper le fil ou non. Chaque fil peut être rayé de multiples couleurs.
C
S | S

S
C | P
C | P | S | N

N
N | B
P | B

B

Se référer à l'annexe B pour identifier les piles. Se référer à l'annexe C pour identifier les ports.

Lettre | Instruction
C | Couper le fil
N | Ne pas couper le fil
S | Couper le fil si le dernier chiffre du numéro de série est pair
P | Couper le fil si la bombe a un port parallèle
B | Couper le fil si la bombe a deux piles ou plus

Le fil contient du
rouge

Le fil contient du
bleu

Il y a le symbole ★

La lumière est
allumée

Keep Talking and Nobody Explodes v. 1-fr | Séquences de fils

## À propos des Séquences de fils

C'est difficile d'expliquer comment ça fonctionne. C'est ingénieux, maisil y avait sûrement un moyen plus simple de gérer neuf fils.

Sur ce module, il y a plusieurs panneaux contenant des fils mais seulement l'un d'eux est visible à la fois. Passer
au panneau suivant en appuyant sur la flèche du bas et au
panneau précédent avec la flèche du haut.
Couper tous les fils du panneau qui doivent être coupés, avant de passer au suivant.
Couper les fils comme décrit sur la table ci-dessous. Le nombre d'apparitions de fils est cumulatif sur tous les panneaux du module.
Apparitions de fils rouges | Apparitions de fils bleus | Apparitions de fils noirs
Apparitionsde fil | Couper si connecté à : | Apparitionsde fil | Couper si connecté à : | Apparitions de fil | Couper si connecté à :
Premier fil rouge | C | Premier fil bleu | B | Premier fil noir | A, B ou C
Deuxième fil rouge | B | Deuxième fil bleu | A ou C | Deuxième fil noir | A ou C
Troisième fil rouge | A | Troisièmefil bleu | B | Troisième fil noir | B
Quatrième fil rouge | A ou C | Quatrième fil bleu | A | Quatrième fil noir | A ou C
Cinquième fil rouge | B | Cinquième fil bleu | B | Cinquième fil noir | B
Sixièmefil rouge | A ou C | Sixième fil bleu | B ou C | Sixième fil noir | B ou C
Septième fil rouge | A, B ou C | Septième fil bleu | C | Septième fil noir | A ou B
Huitièmefil rouge | A ou B | Huitièmefil bleu | A ou C | Huitième fil noir | C
Neuvième fil rouge | B | Neuvième fil bleu | A | Neuvième fil noir | C

Keep Talking and Nobody Explodes v. 1-fr | Fils

## À propos des Fils

Les filssont comme le sang de l'électronique ! Non... L'électricité est le sang. Lesfils sont plus comme les artères. Les veines ? Peu importe...

Un module de fils peut contenir entre 3 et 6 fils.
Seul un fil a besoin d'être coupé pour désarmer le module. Les fils sont ordonnés de haut en bas.

3 fils :
S'il n'y a pas de fil rouge, couper le deuxième fil.
Sinon, si le dernier fil est blanc, couper le dernier fil. Sinon, s'il y a plus d'un fil bleu, couper le dernier fil bleu.
Sinon, couper le dernier fil.

4 fils :
S'il y a plus d'un fil rouge et si le dernier chiffre du numéro de série est impair, couper le dernier fil rouge.
Sinon, si le dernier filest jaune et s'il n'y a pas de fil rouge, couper le premier fil.
Sinon, s'il y a exactement un fil bleu, couper le premier fil.
Sinon, s'il y a plus d'un fil jaune, couper le dernier fil.
Sinon, couper le deuxième fil.

5 fils :
Si le dernier fil est noir et si le dernier chiffre du numéro de série est impair, couper le quatrième fil.
Sinon, s'il y a exactement un fil rouge et plus d'un fil jaune, couper le premier fil.
Sinon, s'il n'y a pas de fil noir, couper le deuxième fil.
Sinon, couper le premier fil.

6 fils :
S'il n'y a pas de fil jaune et si le dernier chiffre du numéro de série est impair, couper le troisième fil.
Sinon, s'il y a exactement un fil jaune et plus d'un fil blanc, couper le quatrième fil.
Sinon, s'il n'y a pas de fil rouge, couper le dernier fil.
Sinon, couper le quatrième fil.

## À propos du Mot de passe

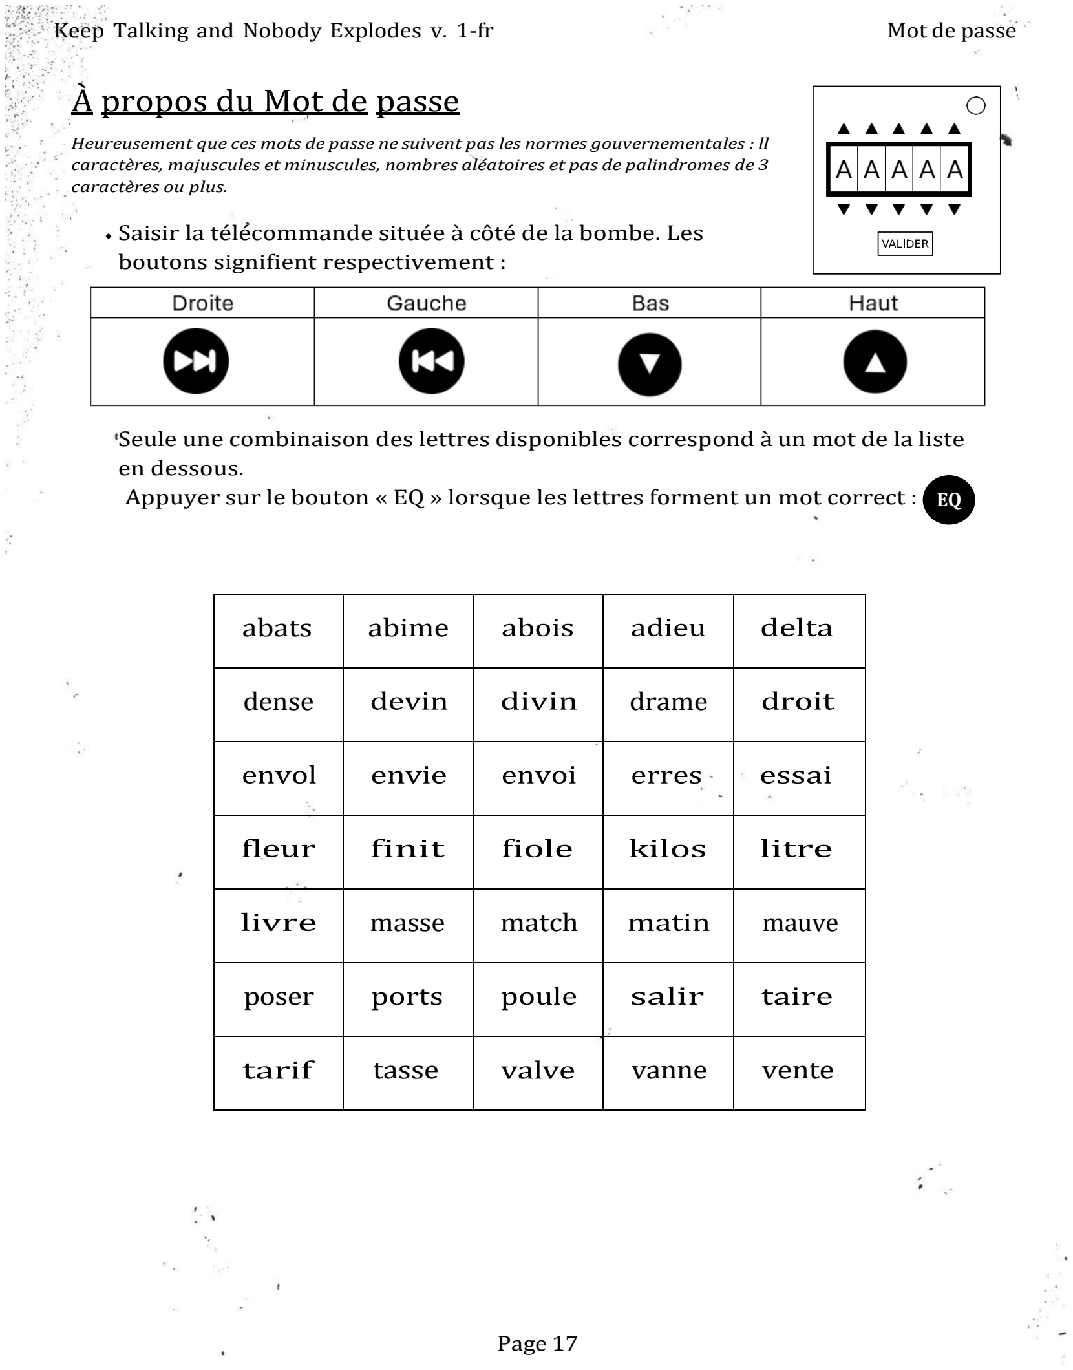
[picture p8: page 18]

Keep Talking and Nobody Explodes v. 1-fr | Mot de passe

Heureusement que ces mots de passe ne suivent pas les normes gouvernementales : ll caractères, majuscules et minuscules, nombres aléatoires et pas de palindromes de 3 caractères ou plus.

Saisir la télécommande située à côté de la bombe. Les boutons signifient respectivement :

Seule une combinaison des lettres disponibles correspond à un mot de la liste en dessous.
Appuyer sur le bouton « EQ » lorsque les lettres forment un mot correct :
abats | abime | abois | adieu | delta
dense | devin | divin | drame | droit
envol | envie | envoi | erres | essai
fleur | finit | fiole | kilos | litre
livre | masse | match | matin | mauve
poser | ports | poule | salir | taire
tarif | tasse | valve | vanne | vente

EQ

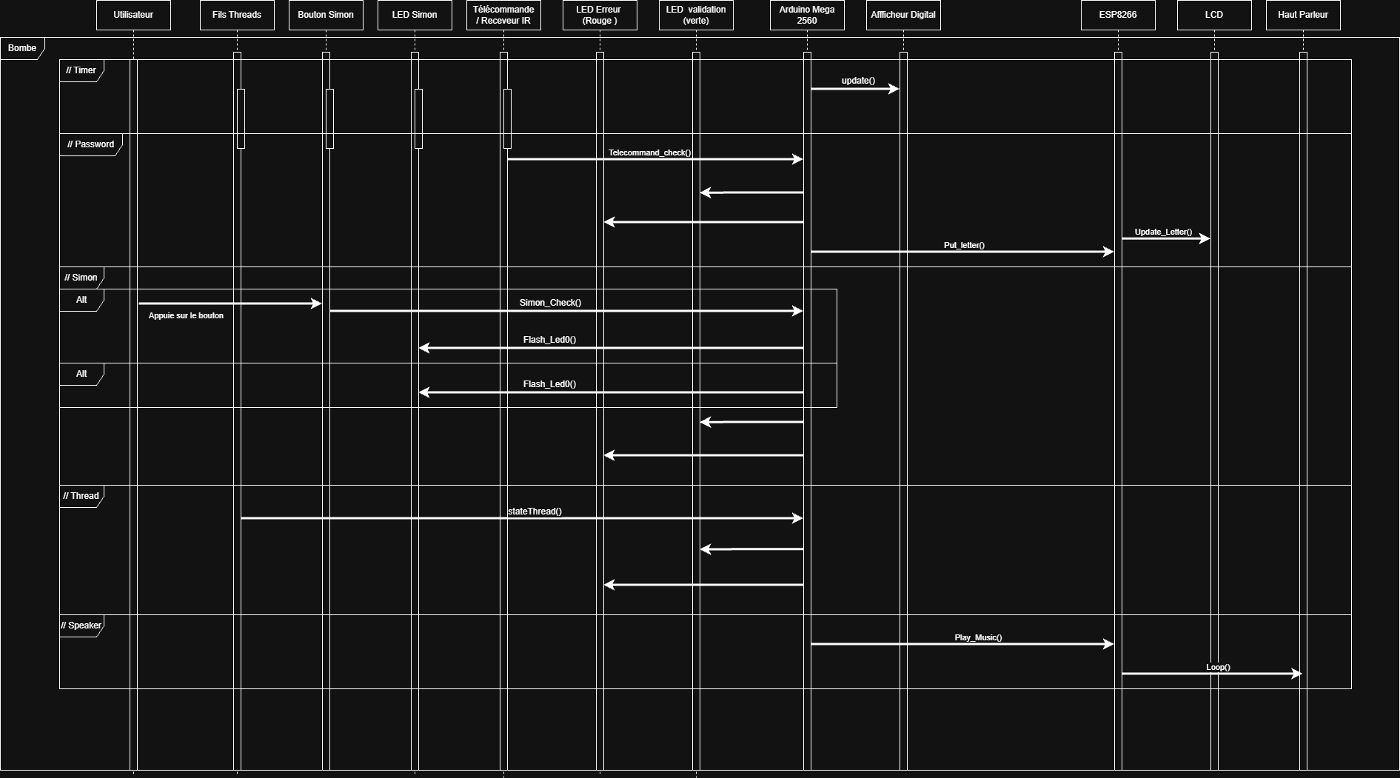
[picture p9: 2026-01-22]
Bombe_Diagramme_Sequence.drawio.png

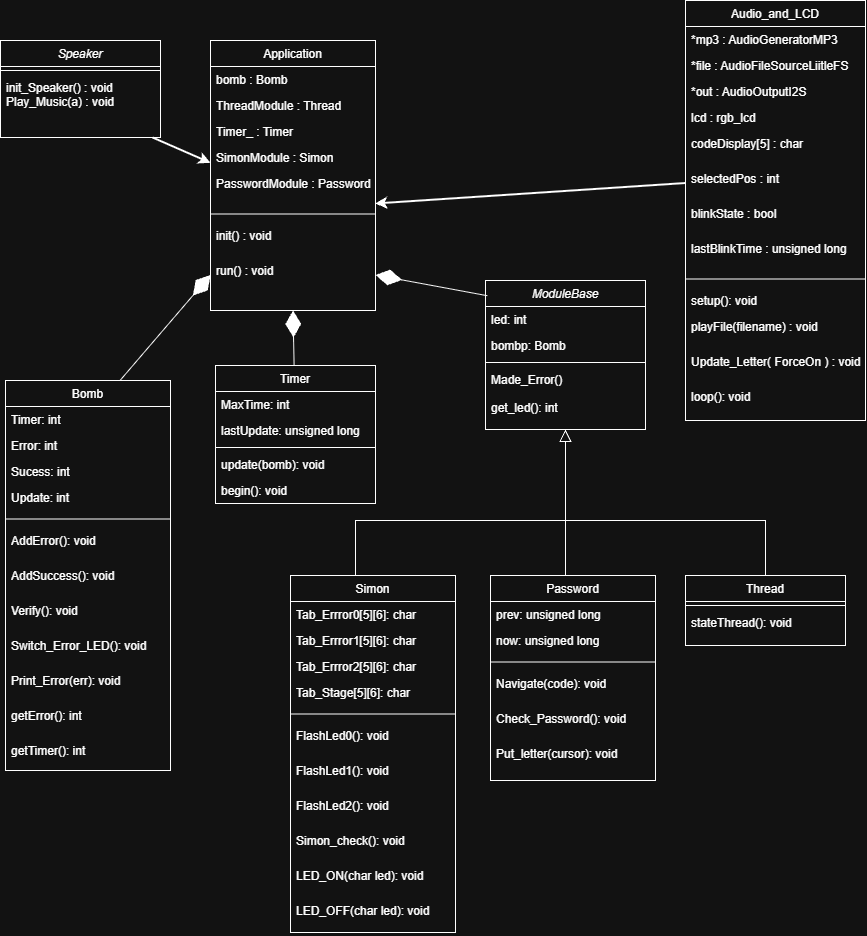
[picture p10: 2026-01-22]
Bomb_Class_diagram.drawio.png

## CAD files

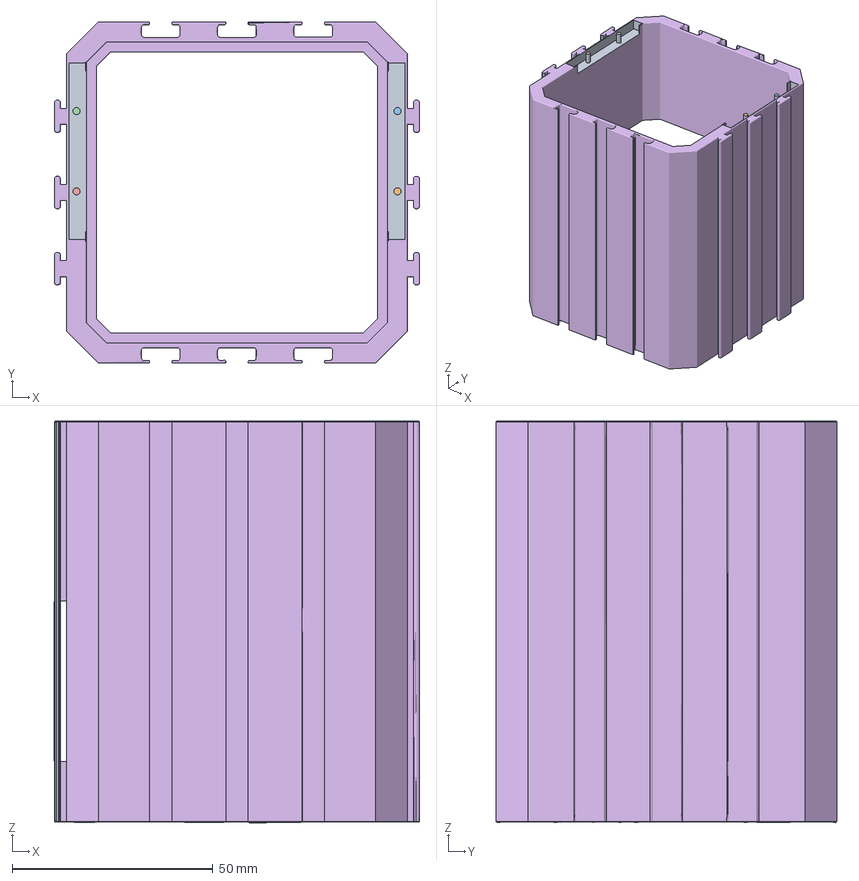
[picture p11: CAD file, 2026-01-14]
3D File/Module LCD/Erreur/lcd_complete3.3mf
91.0 x 85.0 x 100.2 mm
Interlocking_Module_V3 (1)
Interlocking_Module_V3 (2)
Interlocking_Module_V3 (3)
Interlocking_Module_V3 (4)
Interlocking_Module_V3

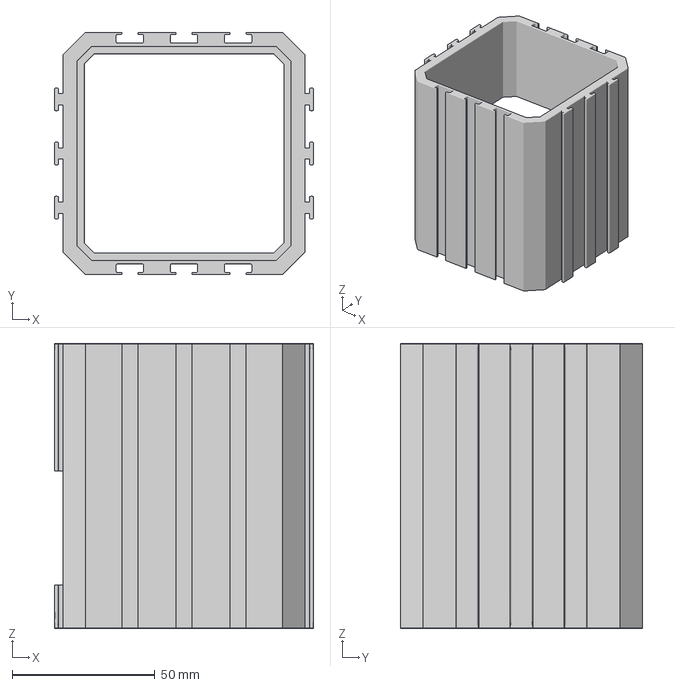
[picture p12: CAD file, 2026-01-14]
3D File/Casier Modulable/Actuel/FInalDrawer.3mf
91.0 x 85.0 x 100.0 mm

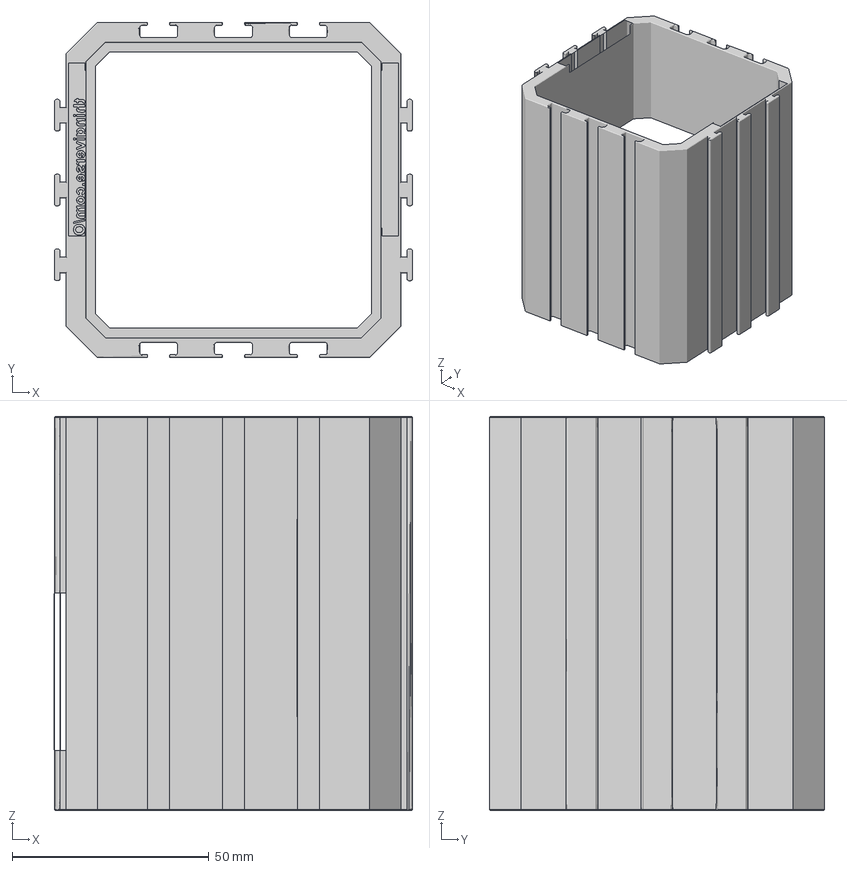
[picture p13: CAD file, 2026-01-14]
3D File/Casier Modulable/Erreur/Interlocking_Module_V3.3mf
91.0 x 85.0 x 100.0 mm

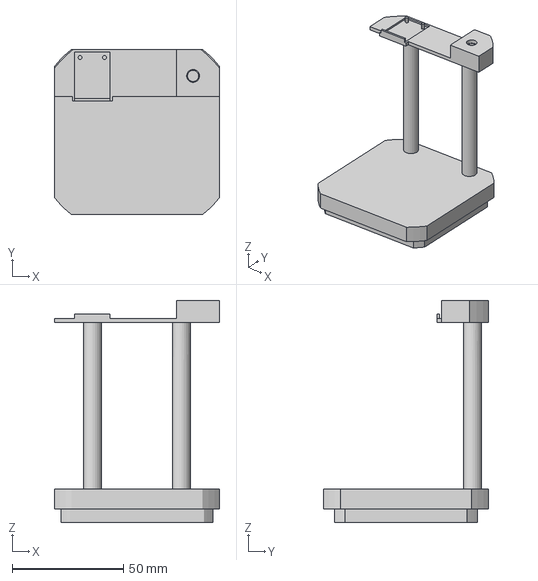
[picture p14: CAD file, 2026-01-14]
3D File/Module Password/Actuel/Password.3mf
74.5 x 74.5 x 100.0 mm

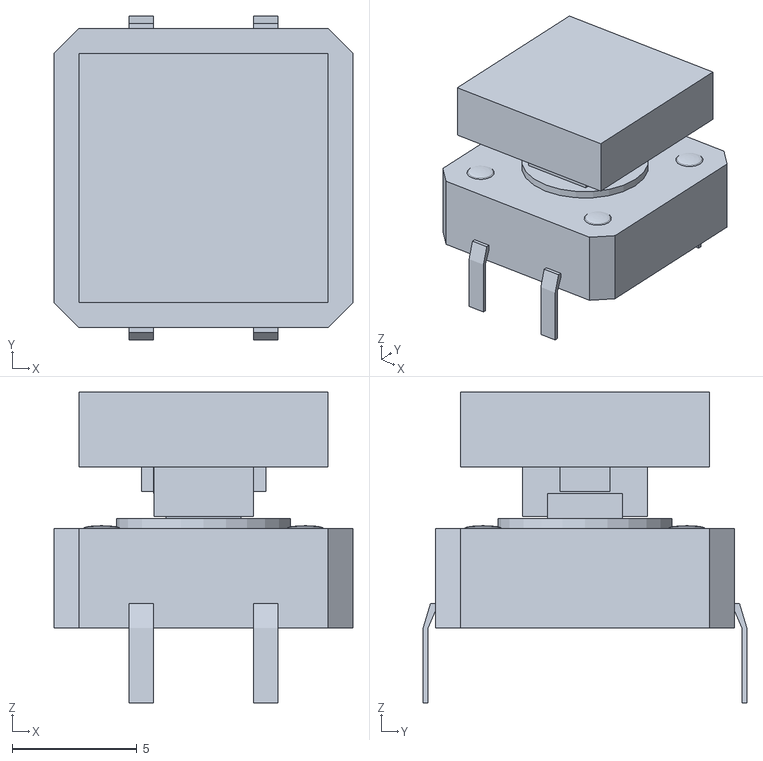
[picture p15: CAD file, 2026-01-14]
3D File/Module Simon/Erreur/button_12x12_push.stl
12.0 x 13.0 x 12.5

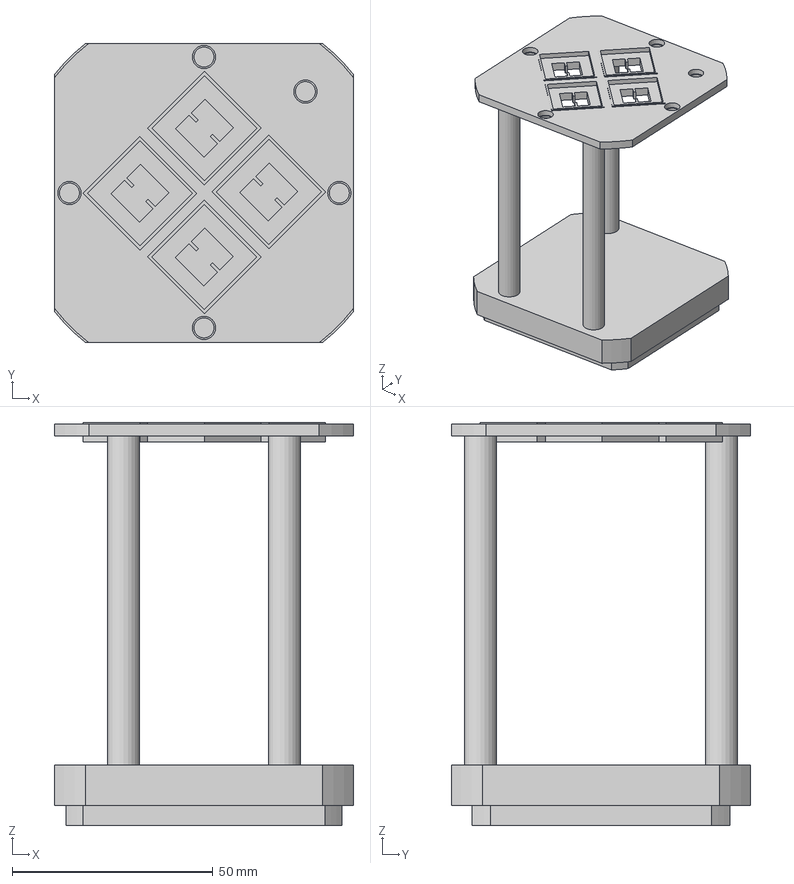
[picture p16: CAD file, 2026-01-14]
3D File/Module Simon/Modelisation_finale/ModuleSimon.3mf
74.5 x 74.5 x 100.3 mm

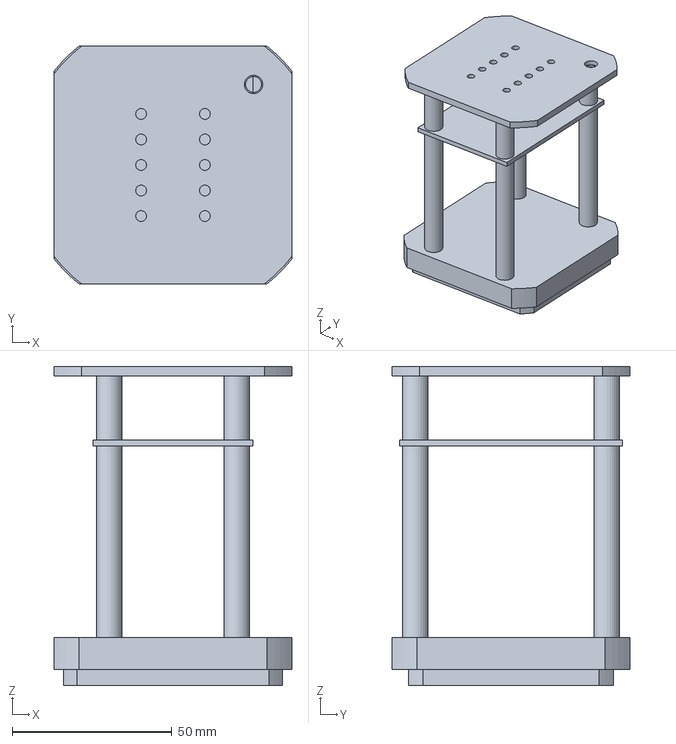
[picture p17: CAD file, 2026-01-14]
3D File/Module Thread/Actuel/CouvercleThreadV1.3mf
74.5 x 74.5 x 100.0 mm

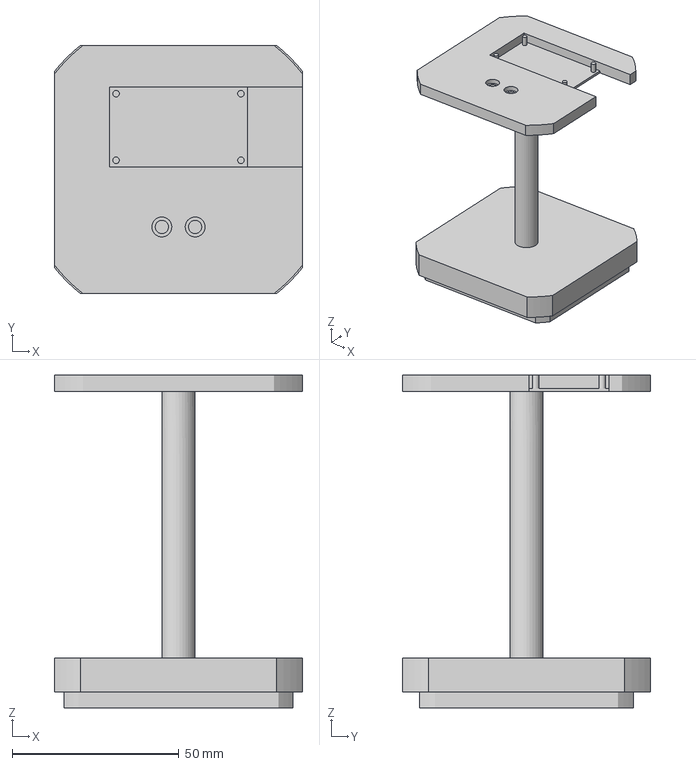
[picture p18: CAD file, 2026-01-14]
3D File/Module Timer/Actuel/Couvercle_Timer6.3mf
74.5 x 74.5 x 100.0 mm

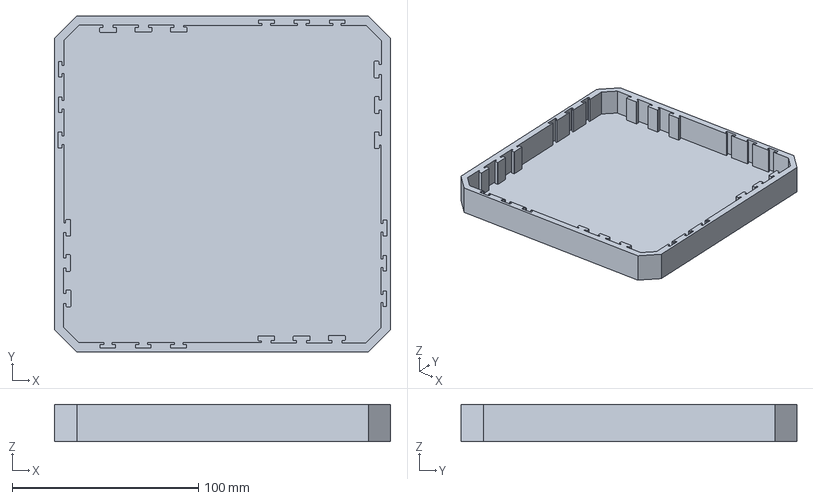
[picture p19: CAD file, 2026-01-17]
3D File/Support/Actuel/Support4.3mf
180.4 x 180.4 x 20.0 mm

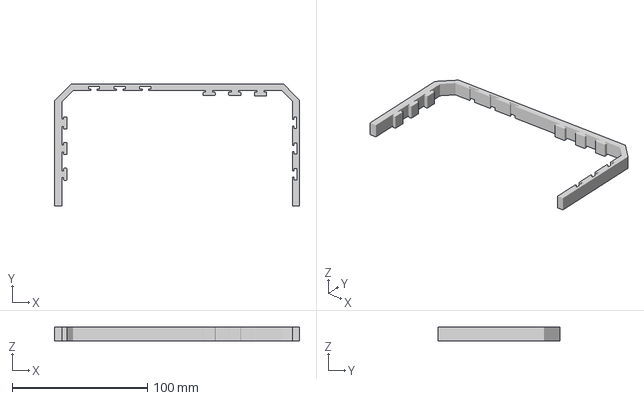
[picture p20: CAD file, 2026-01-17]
3D File/Support/Erreur et tests/Support2.3mf
180.9 x 90.2 x 10.0 mm

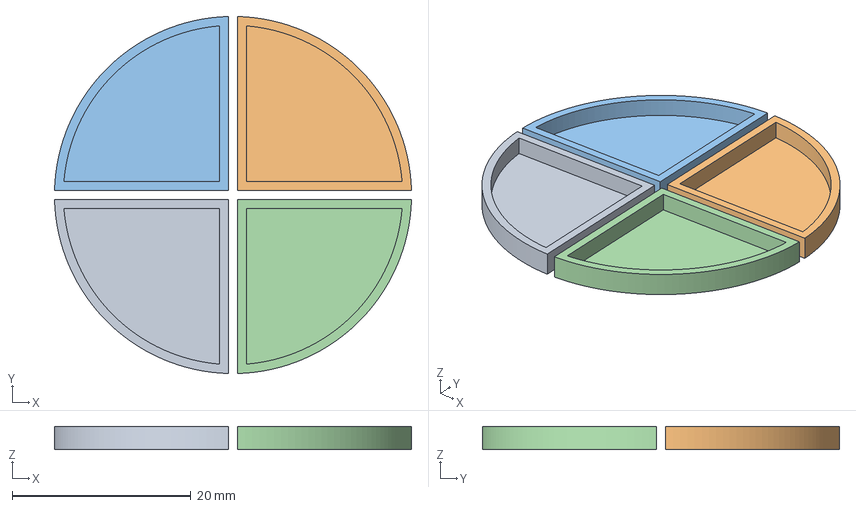
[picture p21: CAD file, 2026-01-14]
3D File/Module Simon/Erreur/Bouton_Simon.3mf
40.0 x 40.0 x 2.60 mm

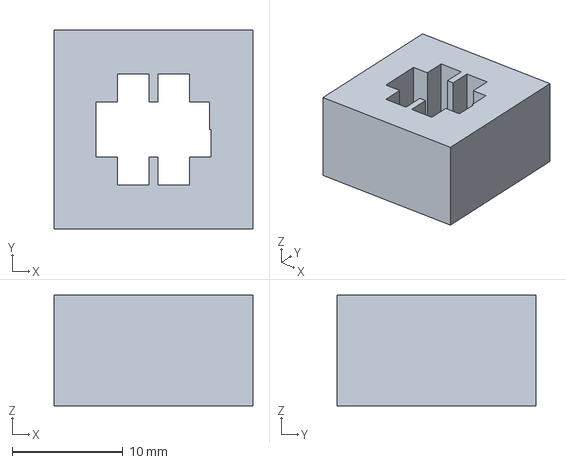
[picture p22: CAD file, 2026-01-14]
3D File/Module Simon/Modelisation_finale/Support_Button_V2.3mf
18.0 x 18.0 x 10.0 mm

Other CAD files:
3D File/Module LCD/Erreur/LCD_CompleteV2.3mf
3D File/Module LCD/Erreur/LCD_Complete.3mf
3D File/Module LCD/Actuel/FinaleLCD.3mf
3D File/Module Password/Erreur/ModulePassword.3mf
3D File/Module Timer/Erreur/Couvercle_Timer5.3mf
3D File/Casier Modulable/Erreur/test2.3mf
3D File/Casier Modulable/Erreur/DrawerCasingV7.3mf
3D File/Casier Modulable/Erreur/DrawerV2.3mf
3D File/Casier Modulable/Erreur/DrawerV3.3mf
3D File/Casier Modulable/Erreur/DrawerV4.3mf
3D File/Casier Modulable/Erreur/DrawerV5.3mf
3D File/Casier Modulable/Erreur/DrawerV6.3mf
3D File/Casier Modulable/Erreur/Drawer_CasingV5.3mf
3D File/Casier Modulable/Erreur/Interlocking_Module_V3.stl
3D File/Casier Modulable/Erreur/drawer2.3mf
3D File/Casier Modulable/Erreur/drawermax.3mf
3D File/Module LCD/Erreur/LCD_CasingV1.3mf
3D File/Module LCD/Erreur/LCD_Drawer.3mf
3D File/Module Simon/Modelisation_finale/6mm+button+PP.3mf
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

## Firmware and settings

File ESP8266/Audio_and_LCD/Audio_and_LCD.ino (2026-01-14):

#include <Arduino.h>
#include <LittleFS.h>                 // Bibliothèque LittleFS faire sortir la musique
#include "AudioFileSourceLittleFS.h"  // Source Audio LittleFS pour lire la musique
#include "AudioGeneratorMP3.h"        // Pour convertir la source en musique
#include "AudioOutputI2S.h"           // Pour envoyer la musique
#include <SoftwareSerial.h>           // Ajouter un port TX/RX pour l'ESP8266
#include <Wire.h>
#include "rgb_lcd.h"
#include <ESP8266WiFi.h>
// --- CONFIGURATION ---
SoftwareSerial Mega(14, 12);  // Tx en 14 et Rx en 12 correspondant à D6 et D5.

// Generation des adresses du Fichier Audio

AudioGeneratorMP3 *mp3;
AudioFileSourceLittleFS *file;
AudioOutputI2S *out;
rgb_lcd lcd;
char codeDisplay[5] = { 'A', 'A', 'A', 'A', 'A' };  // Les lettres actuelles
int selectedPos = 0;                                // Quelle lettre clignote ? (0 à 4)
bool blinkState = true;                             // Pour l'effet clignotant
unsigned long lastBlinkTime = 0;                    // Pour gérer le clignotement

void setup() {
  WiFi.mode(WIFI_OFF); 
  WiFi.forceSleepBegin();
  delay(1);

  Mega.begin(9600);

  lcd.begin(16, 2);
  lcd.setRGB(0, 0, 200);

  if (!LittleFS.begin()) {
    lcd.setRGB(255, 0, 0);
    lcd.print("Err: LittleFS");
    while(1); // On bloque si ça ne marche pas
  }

  out = new AudioOutputI2S();
  out->SetGain(0.4);  // Volume 40%
  mp3 = new AudioGeneratorMP3();

  lcd.clear();
  lcd.setCursor(2, 0);
  lcd.print("Mot de passe :");
  Update_Letter(true);  // Force l'affichage
}

void playFile(String filename) {
  // Arrêt propre si déjà en lecture
  if (mp3->isRunning()) {
    mp3->stop();
  }

  // --- GESTION DU NOM DE FICHIER ---
  // Ajouter .mp3 si manquant
  if (!filename.endsWith(".mp3")) filename += ".mp3";
  // Ajouter le / au début si manquant pour LittleFS
  if (!filename.startsWith("/")) filename = "/" + filename;

  if (LittleFS.exists(filename)) {  // Regarde si le fichier existe ou non
    // 4. NETTOYAGE MÉMOIRE CRITIQUE
    // Si 'file' a déjà été utilisé, on le supprime pour libérer la RAM
    if (file != nullptr) {
      delete file;
      file = nullptr;
    }
    // Lecture avec LittleFS
    file = new AudioFileSourceLittleFS(filename.c_str());
    mp3->begin(file, out);
  }
}

void Update_Letter(bool ForceOn) {  // ForceOn sert au moment ou on ne veut plujs clignoter
  int positions[5] = { 2, 5, 8, 11, 14 };
  for (int i = 0; i < 5; i++) {
    lcd.setCursor(positions[i], 1);

    if (i == selectedPos) {
      if (blinkState or ForceOn) {
        lcd.print(codeDisplay[i]);
      } else {
        lcd.print(" ");
      }
    }
    else
      lcd.print(codeDisplay[i]);
  }
}

void loop() {
  // 1. Moteur Audio
  if (mp3->isRunning()) {
    if (!mp3->loop()) {
      mp3->stop();
    }
  }

  if (millis() - lastBlinkTime > 500) {
    lastBlinkTime = millis();
    blinkState = !blinkState;
    Update_Letter(false);
  }

  // 2. Ecoute du Mega
  if (Mega.available()) {
    String command = Mega.readStringUntil('\n');
    command.trim();
    if (command.startsWith("SEL:")) {
      selectedPos = command.substring(4).toInt();
      blinkState = true;
      Update_Letter(true);
    } else if (command.startsWith("SET:")) {
      int pos = command.charAt(4) - '0';  // On récupère le chiffre à la position 4

      char letter = command.charAt(6);  // On récupère la lettre à la position 6

      codeDisplay[pos] = letter;
      Update_Letter(true);
    } else if (command.startsWith("PLAY:")) {
      String soundName = command.substring(5);
      playFile(soundName);
    }
  }
}

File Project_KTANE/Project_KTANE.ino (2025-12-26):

#include "Application.h"
#include <TM1637Display.h>

#define CLK 2
#define DIO 3
TM1637Display display(CLK, DIO);  // Défini ici pour garantir l'ordre d'initialisation

Application myApplication;

void setup() 
{
  // put your setup code here, to run once:
  myApplication.init();
}



void loop() 
{
  // put your main code here, to run repeatedly:
  myApplication.run();

}

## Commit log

2025-12-19 Ajout Class Wire Ajout de l'adressage de la bombe dans le ModuleBase Ajout des differentes constantes de la bombe à définir à chaque configuration Ajout d'une methode pour ajouter une error
    [Bombe.cpp]
2025-12-19 Gestion des LED et du Timer pour les erreurs
2025-12-20 Gestion des LED et de l'affichage pour les erreurs
2025-12-20 Test des fils avec la gestion des erreurs, SUCCESS !!!
2025-12-22 Réalisation du Timer ( 5 min ). Mise en place d'un timer par interruption.
2025-12-25 Refonte du timer et correction des erreurs... Allumage de la LED si succès et optimisation du code ( module thread )
    [Bombe.cpp, Thread.cpp]
2025-12-26 Correction du Timer avec ajout de la surcharge d'opérateur
    [Thread.cpp]
2025-12-26 Suppression de l'interruption car trop compliqué et utilisation de la fonction millis() à la place. Ajout du pin de la LED de validation module Thread
2025-12-26 Update README.md
    Update du README pour ajouter les fonctionnalités du timer et des fils
2025-12-26 Suppression des opérateurs de surcharge qui ne servent plus...
2025-12-30 Update README.md
    Module Simon fait. En attente de test pour corriger les éventuels erreurs
2026-01-07 Ajout des commentaires pour expliquer les fonctions.
2026-01-08 Ajout de la fonction Haut parleur
2026-01-09 Le Simon fonctionne avec la validation, il faut encore mettre les erreurs mais c'est easy.
2026-01-09 Vérification erreur, validation led, rectificatif bombe
2026-01-09 Ajout de la class Password, pas encore testé mais sans erreur de compilation. Il reste à faire celui de l'esp.
2026-01-14 Ajout de commentaires, complétion du readme, correction de bug de son.
    [Bombe.cpp, Password.cpp]
2026-01-14 Oubli des fichiers
    [6mm+button+PP.3mf, Bouton_Simon.3mf, CouvercleThreadV1.3mf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]
2026-01-15 Update README.md
    J'ai rajouté le problème de la gestion d'erreurs avec exceptions
2026-01-17 Ajout de fichiers 3d et du manuel de désamorçage
    [Support v5.3mf, Support2.3mf, Support4.3mf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]
2026-01-17 Ajout de fichiers 3d et du manuel de désamorçage + ajout de commentaire
2026-01-22 Diagramme de séquence
2026-01-22 Diagramme de classe
2026-01-22 Diagramme de classe 2
